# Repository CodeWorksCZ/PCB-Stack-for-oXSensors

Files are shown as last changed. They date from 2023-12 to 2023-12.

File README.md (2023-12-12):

# PCB Stack for oXSensors

This PCB design focuses on creating a minimalistic and efficient PCB stack for OpenXSensor project  https://github.com/mstrens/oXs_on_RP2040 , incorporating essential features such as Li-PoL  individuall cell measurement, temperature measurement using NTC, and seamless integration with external GPS modules and on-board BMP280.

This version incorporates temperature measurement using a 10K NTC thermistor, which is not originally accounted for in the [firmware](https://github.com/mstrens/oXs_on_RP2040). Therefore, a minor code addition and code compiling is necessary.

The PCB stack can be powered by standard 5V or can handle up to 12V by configuring the solder pads. This can be useful when operating high-voltage (HV) servos at 8.4V.

**Top PCB Connectors**:

- NTC 10K Thermistor
- RPM -> to CDI
- ACS758 Current Sensor and Voltage measurement

**Bottom PCB Connectors:**

- Li-Pol Cells Measurement (up to 4S) connected to on-board ADS1115
- GPS Module - e.g. BN-220
- ACS758 Current Sensor and Voltage measurement

**PCB Stack Connectors:**

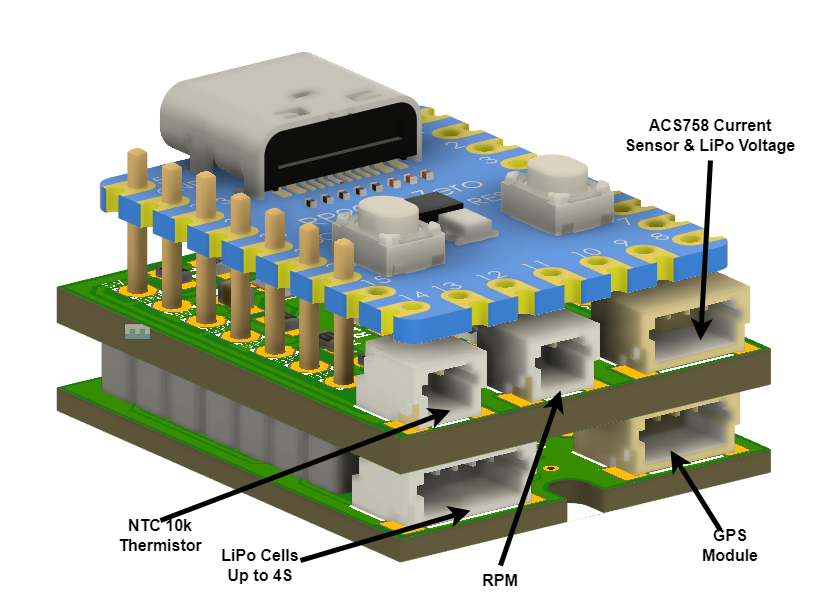
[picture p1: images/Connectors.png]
Connectors


Wiring and assembly instructions can be found in https://github.com/CodeWorksCZ/PCB-Stack-for-oXSensors/wiki

The initial version lacks the capability to connect additional I2C devices.

**Wiring diagram**

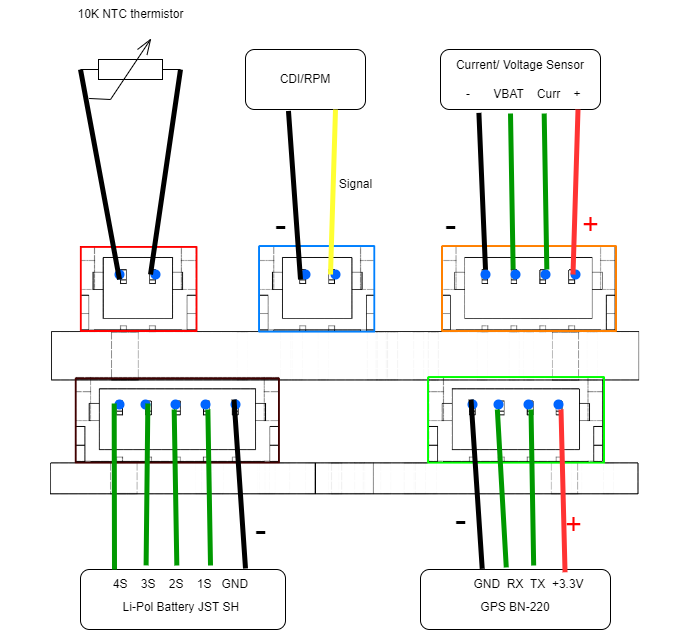
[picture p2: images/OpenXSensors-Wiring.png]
Wiring


Precompiled firmware with the temperature calculation  based on NTC thermistor values can be [here](/oXs%20Firmware/).

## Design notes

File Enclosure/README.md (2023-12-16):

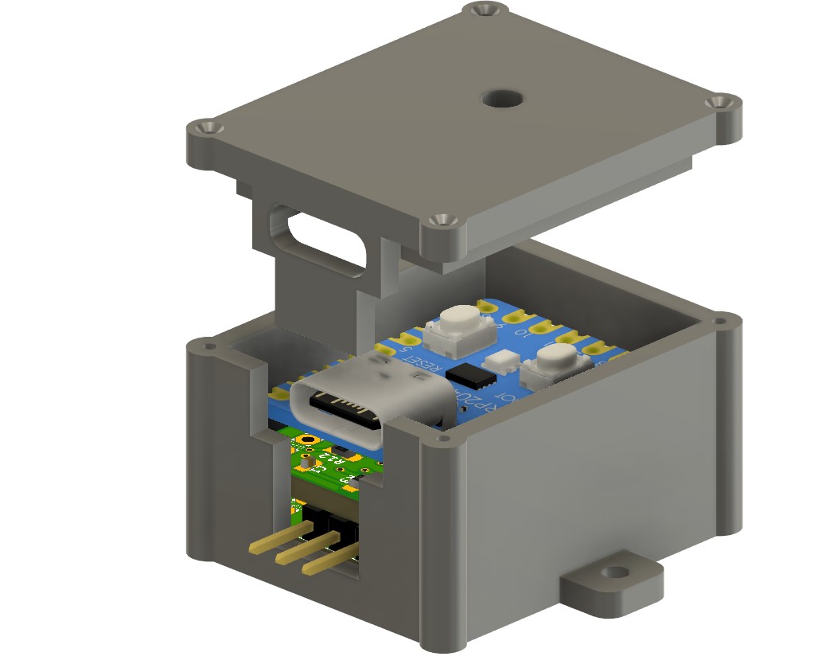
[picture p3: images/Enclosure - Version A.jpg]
Connectors


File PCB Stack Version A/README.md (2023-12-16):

| Bottom PCB | Description |
|---	|---	|
| Bottom.brd	| Eagle Board design of Bottom PCB	|
| Bottom.sch	| Eagle Schematics of Bottom PCB	|
| Bottom.pdf	| Schematics in PDF	|
| Top.brd	| Eagle Board design of Top PCB	|
| Top.sch	| Eagle Schematics of Top PCB	|
| Top.pdf | Schematics in PDF	|
| PCB Stack oXs.f3z	| Fusion360 Files	|

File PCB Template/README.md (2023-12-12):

This is the original template for both the Top and Bottom PCB. Use this if you need to accommodate more PCB layers.

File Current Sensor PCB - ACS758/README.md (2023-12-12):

This PCB is designed for direct connection to JST-SH connector on PCB Stack. It allows to measure current as well as voltage on connected Li-Pol battery.

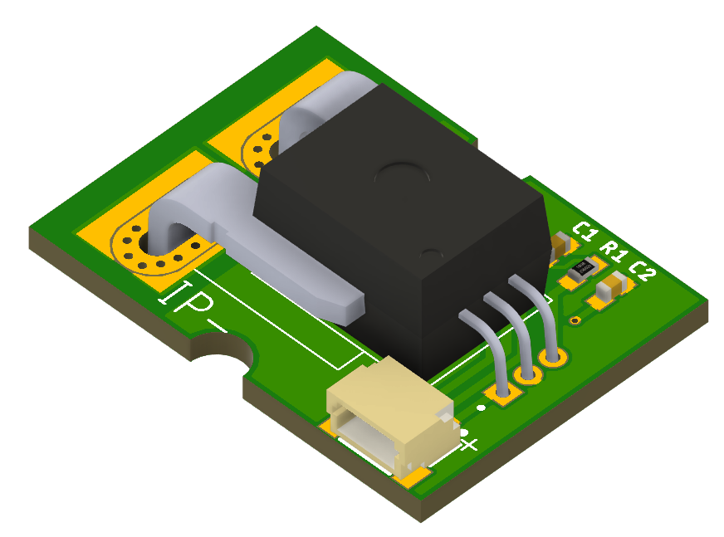
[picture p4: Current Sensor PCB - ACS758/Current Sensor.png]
Current Sensor


**PART LIST**

|Part|Value |Device |Package |Description |
|----|---|---|---|---|
|C1  |1.0uF |1.0UF-0603-16V-10% |0603 |1µF ceramic capacitors|
|C2  |1.0uF |1.0UF-0603-16V-10% |0603 |1µF ceramic capacitors|
|R1  |120R |RESISTOR0603 |0603 |Generic Resistor Package|
|U$1 | |JST-SH-4PINJST-SH-4-HORIZONTAL|JST-SH-4PIN-1.0MM |JST-SH-4PIN-1.0MM
|U1  |ACS758LCB-100B-PFF-T|ACS758LCB-100B-PFF-T |XDCR_ACS770KCB-150U-PFF-T|Thermally Enhanced, Fully Integrated|

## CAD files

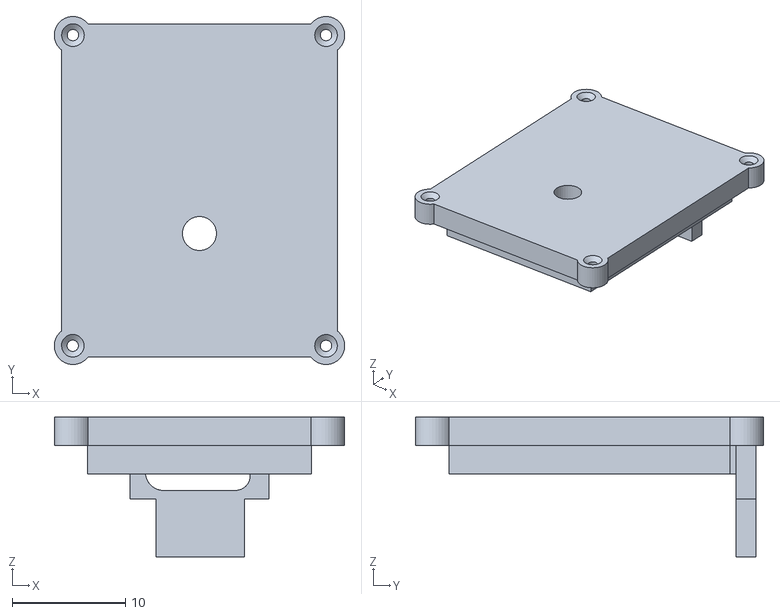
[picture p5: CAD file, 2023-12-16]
Enclosure/Top Part - Version A.stl
25.6 x 30.7 x 12.3

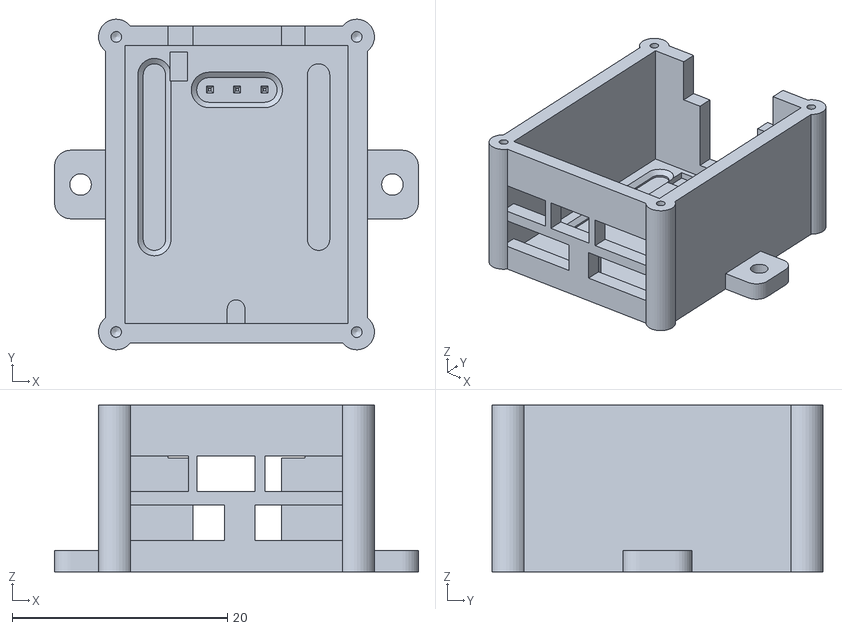
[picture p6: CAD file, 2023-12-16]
Enclosure/Lower Part - Version A.stl
33.8 x 30.7 x 15.5

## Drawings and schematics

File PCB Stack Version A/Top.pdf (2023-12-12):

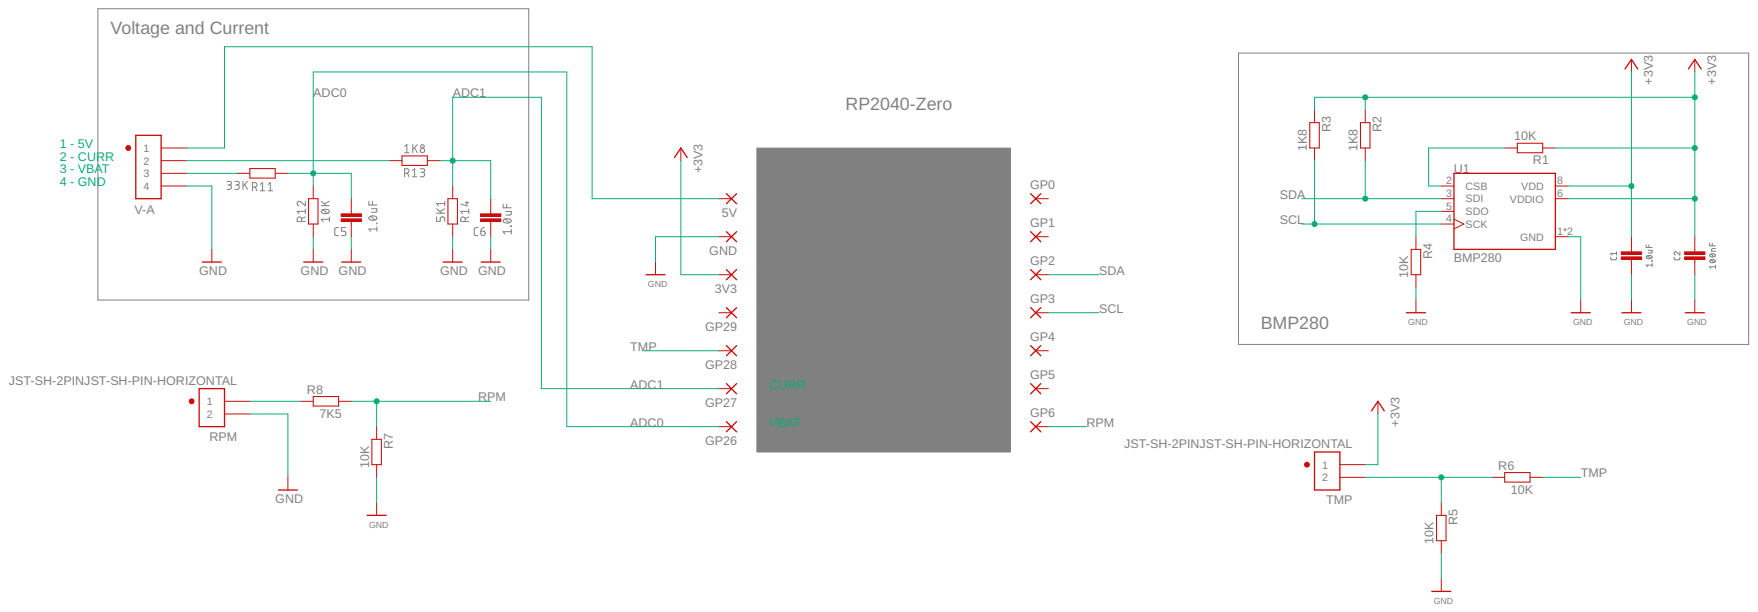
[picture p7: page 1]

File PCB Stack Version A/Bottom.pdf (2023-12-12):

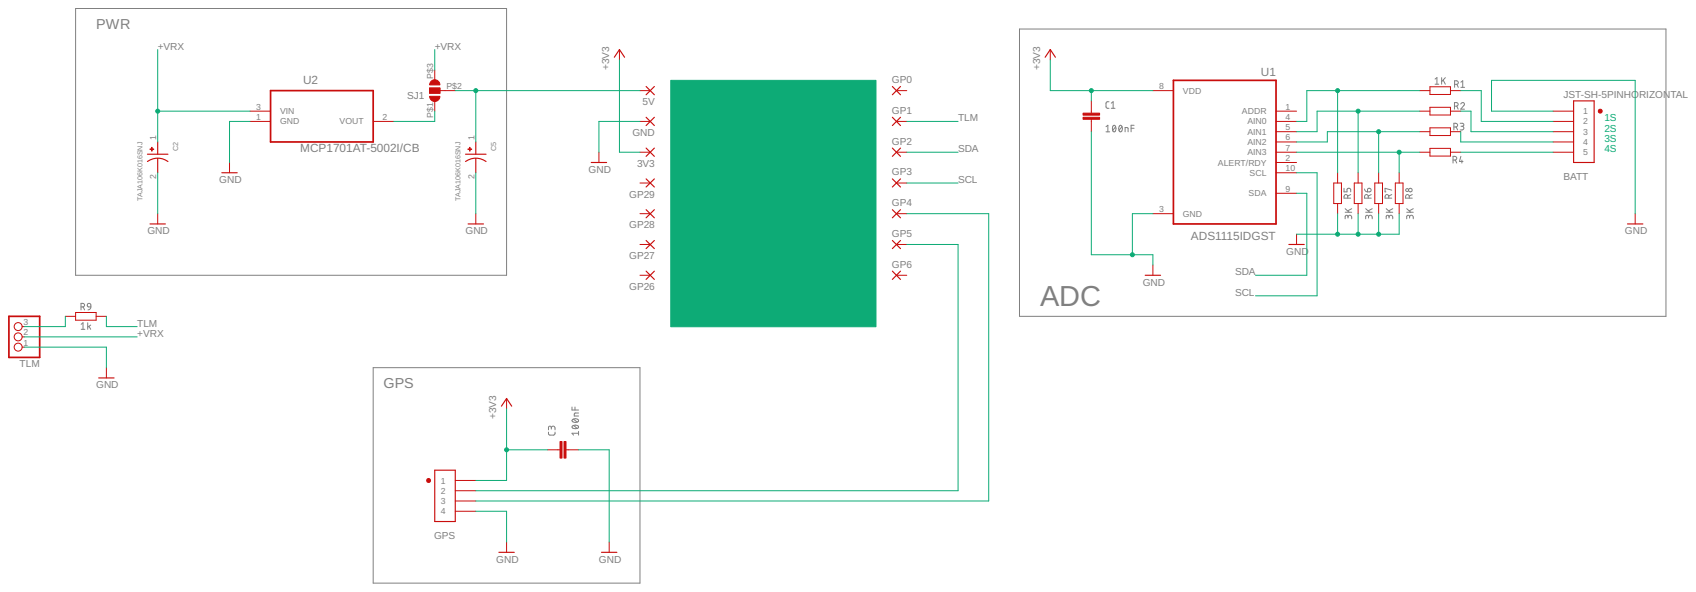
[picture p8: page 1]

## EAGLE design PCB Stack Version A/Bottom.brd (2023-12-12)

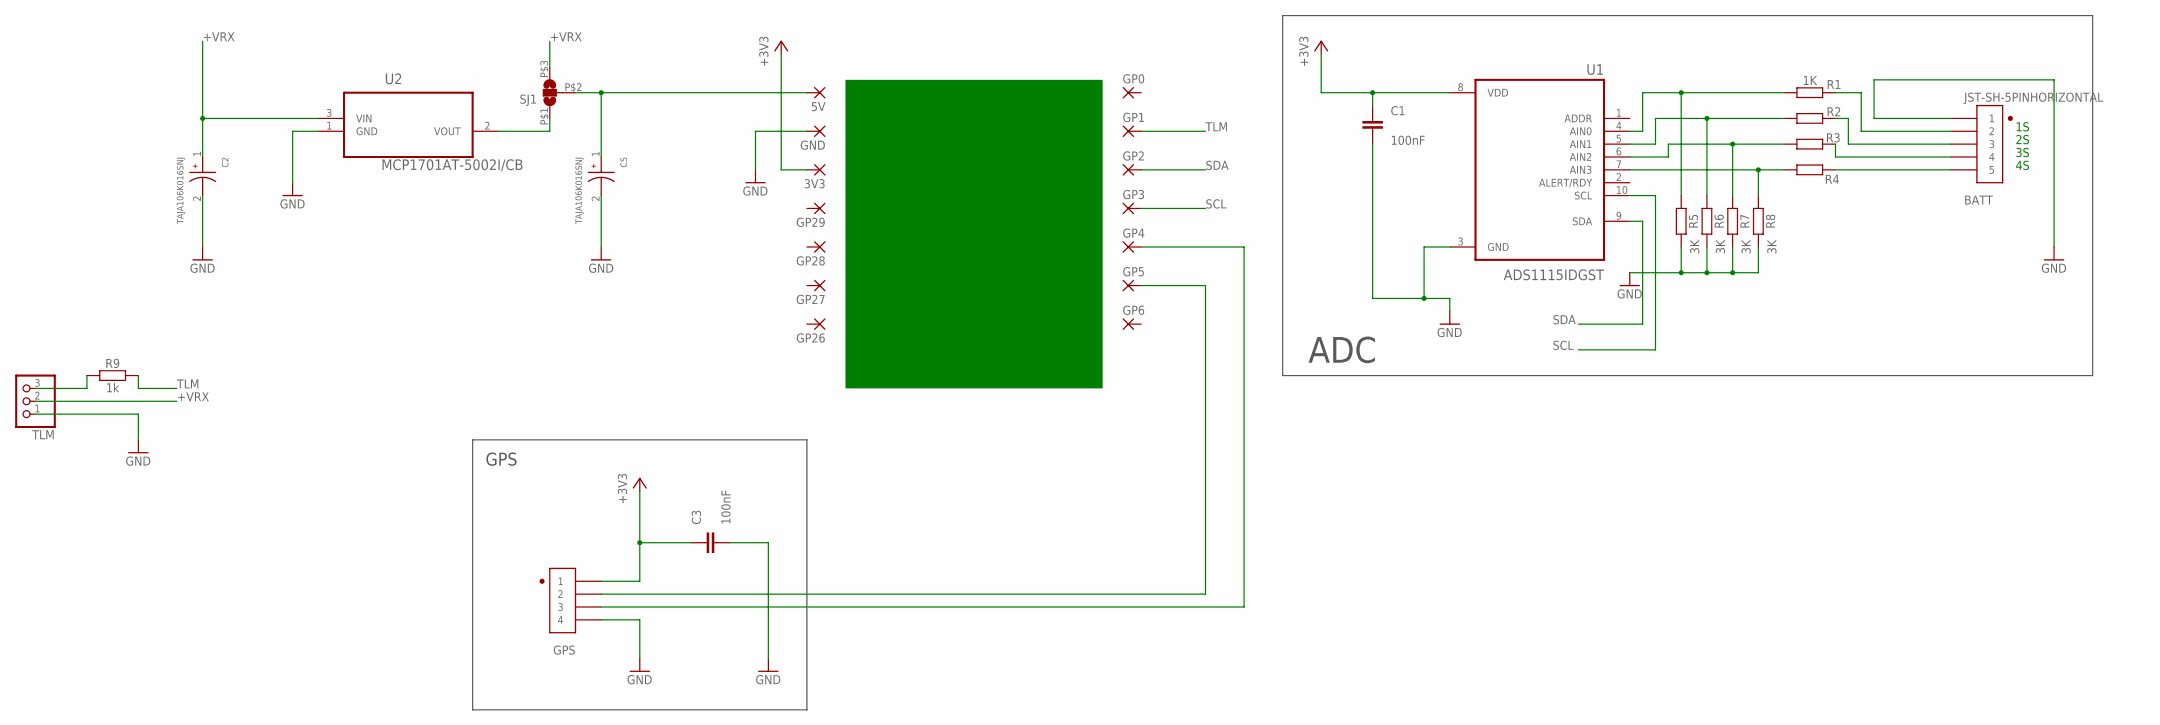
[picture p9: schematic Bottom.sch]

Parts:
3V3, 5V: 1,6/0,9
BATT: JST-SH-5PINHORIZONTAL; JST-SH-5PIN-1.0MM
C1, C3: 100nF; 0603
C2, C5: TAJA106K016SNJ; CAPMP3216X180N
GND: 1,6/0,9
GP0, GP1, GP2, GP3, GP4, GP5, GP6, GP26, GP27, GP28, GP29: 1,6/0,9
GPS: JST-SH-4PINJST-SH-4-HORIZONTAL; JST-SH-4PIN-1.0MM
R1: 1K; 0603
R2, R3, R4: 0603
R5, R6, R7, R8: 3K; 0603
R9: 1k; 0603
SJ1: SJ2WSJ_TINY; SJ_TINY
TLM: PINHD-1X390; 1X03-ANGLE
U1: ADS1115IDGST; SOP50P490X110-10N
U2: MCP1701AT-5002I/CB; SOT95P255X145-3N

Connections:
+3V3: 3V3.1, C1.1, C3.1, GPS.1, U1.8 (VDD)
+VRX: C2.1, SJ1.P$3 (3), TLM.2, U2.3 (VIN)
GND: BATT.1, C1.2, C2.2, C3.2, C5.2, GND.1, GPS.4, R5.2, R6.2, R7.2, R8.2, TLM.1, U1.3 (GND), U2.1 (GND)
unnamed: R1.2, R5.1, U1.4 (AIN0)
unnamed: R2.2, R6.1, U1.5 (AIN1)
unnamed: R3.2, R7.1, U1.6 (AIN2)
unnamed: R4.2, R8.1, U1.7 (AIN3)
unnamed: BATT.5, R4.1
unnamed: BATT.4, R3.1
unnamed: BATT.3, R2.1
unnamed: BATT.2, R1.1
unnamed: R9.1, TLM.3
unnamed: GP4.1, GPS.3
unnamed: GP5.1, GPS.2
unnamed: SJ1.P$1 (1), U2.2 (VOUT)
unnamed: 5V.1, C5.1, SJ1.P$2 (2)
SCL: GP3.1, U1.10 (SCL)
SDA: GP2.1, U1.9 (SDA)
TLM: GP1.1, R9.2

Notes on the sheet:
GPS
ADC

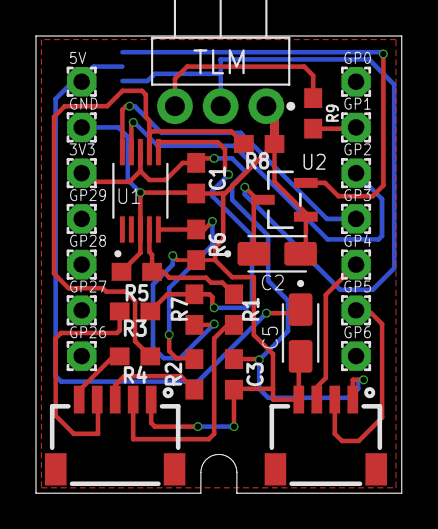
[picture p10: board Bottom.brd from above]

Board: 2 copper layers, 20.3 x 25.4 mm, 33 parts (1 on the bottom side), 19 nets.

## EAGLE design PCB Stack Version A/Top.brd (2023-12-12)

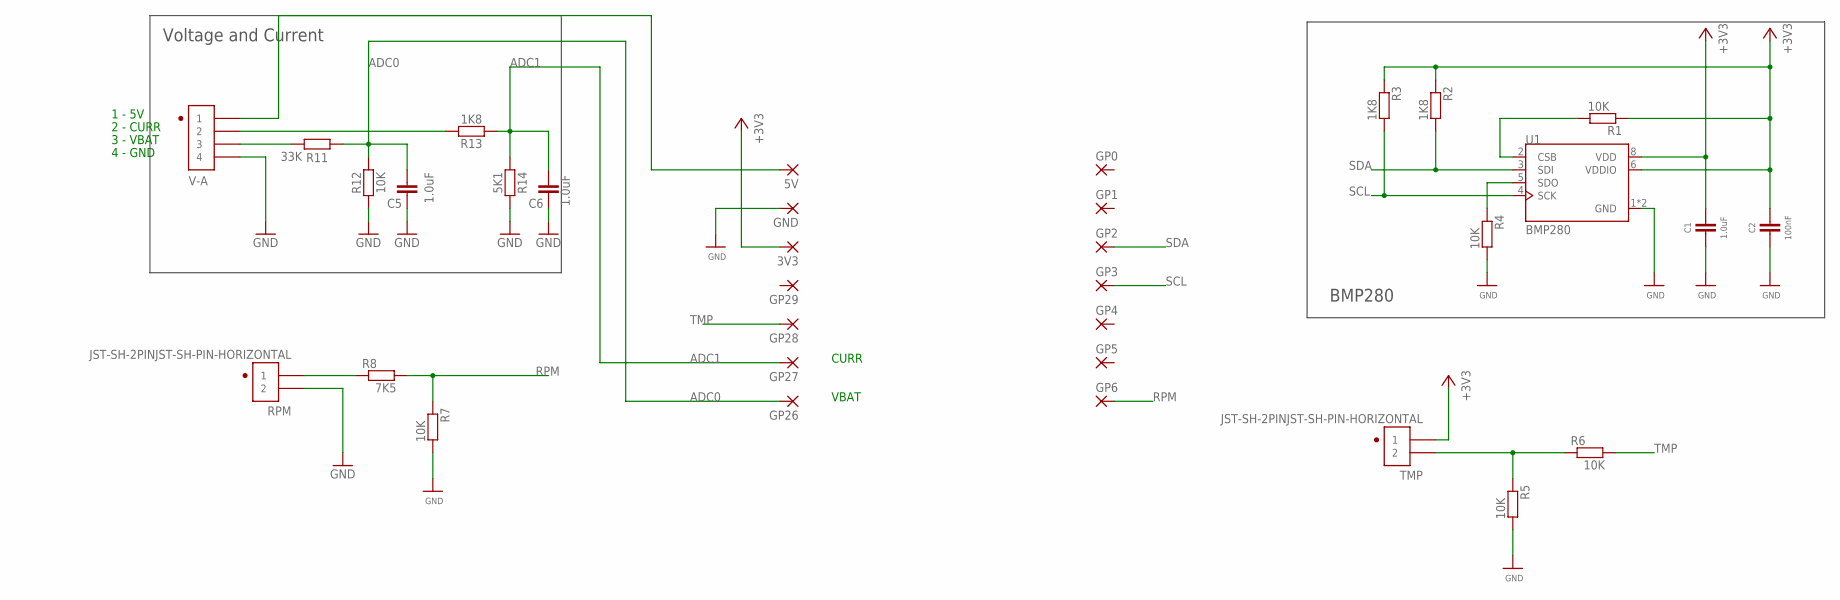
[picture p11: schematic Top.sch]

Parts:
3V3, 5V: 1,6/0,9
C1: 1.0uF; 0402
C2: 100nF; 0603
C5, C6: 1.0uF; 0603
GND: 1,6/0,9
GP0, GP1, GP2, GP3, GP4, GP5, GP6, GP26, GP27, GP28, GP29: 1,6/0,9
R1, R4, R5, R6, R7, R12: 10K; 0603
R2, R3, R13: 1K8; 0603
R8: 7K5; 0603
R11: 33K; 0603
R14: 5K1; 0603
RPM: JST-SH-2PINJST-SH-PIN-HORIZONTAL; JST-SH-2PIN-1.0MM
TMP: JST-SH-2PINJST-SH-PIN-HORIZONTAL; JST-SH-2PIN-1.0MM
U1: BMP280; XDCR_BMP280
V-A: JST-SH-4PINJST-SH-4-HORIZONTAL; JST-SH-4PIN-1.0MM

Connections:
+3V3: 3V3.1, C1.1, C2.1, R1.1, R2.1, R3.1, TMP.1, U1.6 (VDDIO), U1.8 (VDD)
ADC0: C5.2, GP26.1, R11.2, R12.2
ADC1: C6.2, GP27.1, R13.1, R14.1
GND: C1.2, C2.2, C5.1, C6.1, GND.1, R4.2, R5.2, R7.2, R12.1, R14.2, RPM.2, U1.1 (GND), U1.7 (GND), V-A.4
unnamed: R1.2, U1.2 (CSB)
unnamed: R4.1, U1.5 (SDO)
unnamed: R5.1, R6.1, TMP.2
unnamed: R8.1, RPM.1
unnamed: R11.1, V-A.3
unnamed: R13.2, V-A.2
unnamed: 5V.1, V-A.1
RPM: GP6.1, R7.1, R8.2
SCL: GP3.1, R3.2, U1.4 (SCK)
SDA: GP2.1, R2.2, U1.3 (SDI)
TMP: GP28.1, R6.2

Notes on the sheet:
BMP280
Voltage and Current
1 - 5V
2 - CURR
3 - VBAT
4 - GND
VBAT
CURR

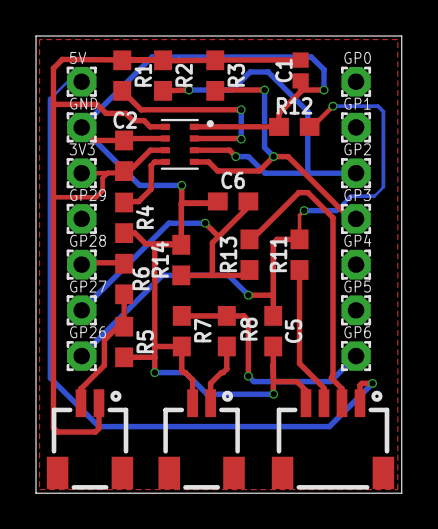
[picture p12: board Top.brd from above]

Board: 2 copper layers, 20.3 x 25.4 mm, 34 parts (0 on the bottom side), 15 nets.

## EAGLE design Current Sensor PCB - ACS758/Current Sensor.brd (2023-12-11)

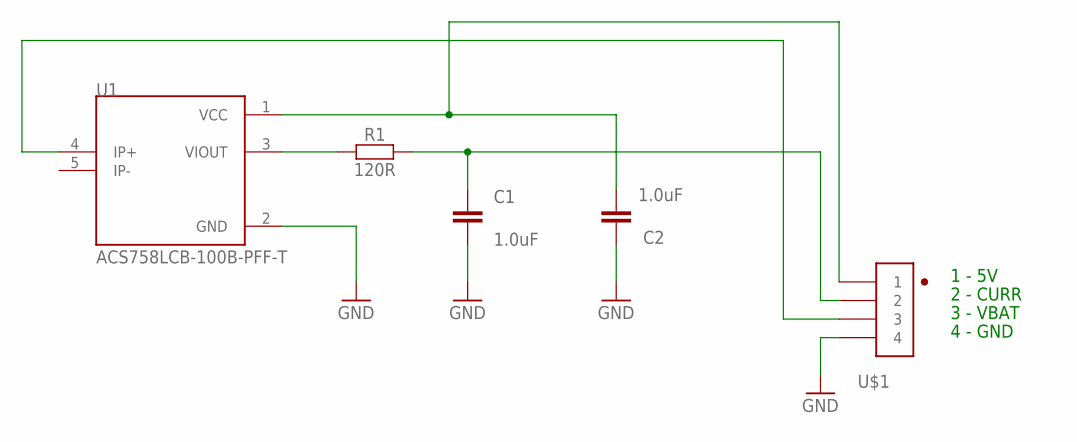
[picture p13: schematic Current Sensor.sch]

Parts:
C1, C2: 1.0uF; 0603
R1: 120R; 0603
U1: ACS758LCB-100B-PFF-T; XDCR_ACS770KCB-150U-PFF-T
U$1: JST-SH-4PINJST-SH-4-HORIZONTAL; JST-SH-4PIN-1.0MM

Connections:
GND: C1.2, C2.1, U1.2 (GND), U$1.4
unnamed: R1.1, U1.3 (VIOUT)
unnamed: C1.1, R1.2, U$1.2
unnamed: U1.4 (IP+), U$1.3
unnamed: C2.2, U1.1 (VCC), U$1.1

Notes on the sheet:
1 - 5V
2 - CURR
3 - VBAT
4 - GND

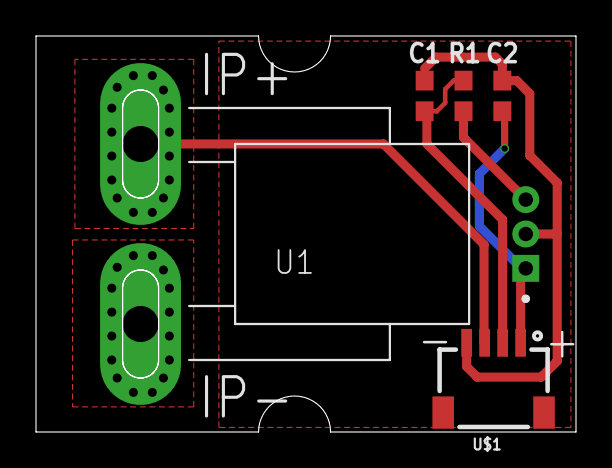
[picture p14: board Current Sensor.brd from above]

Board: 2 copper layers, 30.0 x 22.0 mm, 5 parts (0 on the bottom side), 5 nets.

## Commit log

2023-12-11 Added Currect Sensor Folder
    [Current Sensor.brd, Current Sensor.sch]
2023-12-11 More description added
    [config.txt]
2023-12-11 Added Enclosure
2023-12-12 PCB Added
    [Bottom.brd, Bottom.sch, Template.brd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]
2023-12-12 PCB Schematics and boards added
    [Bottom.sch, Template.brd, Template.sch]
2023-12-12 Voltage Divider and PIN list xls added
    [Resistors - ADS1115.xlsx, Template.brd, Template.sch]
2023-12-12 2.11.0 oXs firmware added
    [config.txt]
2023-12-16 Enclosure STL
    [Lower Part - Version A.stl, Top Part - Version A.stl]
2023-12-16 Enclosure Image added
